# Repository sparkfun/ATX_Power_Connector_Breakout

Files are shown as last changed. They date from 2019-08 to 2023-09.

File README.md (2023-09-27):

SparkFun ATX Power Connector Breakout - 12V/5V (4-pin)
========================================

<table class="table table-hover table-striped table-bordered">
  <tr align="center">
   <td><a href="https://www.sparkfun.com/products/15035">SparkFun ATX Power Connector Breakout - 12V/5V (4-pin)</a></td>
   <td><a href="https://www.sparkfun.com/products/15701">SparkFun ATX Power Connector Breakout Kit - 12V/5V (4-pin)</a></td>
  </tr>
  <tr align="center">
    <td><i>SparkFun ATX Power Connector Breakout - 12V/5V (4-pin) <a href="https://www.sparkfun.com/products/15035">(BOB-15035)</a></i></td>
    <td><i>SparkFun ATX Power Connector Breakout Kit - 12V/5V (4-pin) <a href="https://www.sparkfun.com/products/15701">(KIT-15701)</a></i></td>
  </tr>
</table>

Do you need to power a project with 12V and 5V from one power supply? The ATX power connector breakout board breaks out the standard 4-pin computer peripheral port when mated with an ATX connector [(PRT-15700)](https://www.sparkfun.com/products/15700) for your 12V and 5V devices! Once you have chosen a power supply (whether it be an ATX power supply or the 12V/5V wall adapter), you're ready to give your project some life! This kit has everything you need (including a 12V/5V power supply) to solder together an ATX breakout and screw terminals to power your project directly or pump power into a breadboard using standard headers. 

ATX power supplies usually have a number of power connectors available to power components for a desktop computer.  One of these connectors is the 4-pin power connector, which is intended to power 12V and 5V computer peripherals (such as disk drives). Depending on the manufacturer of the power supply, the quantity of each connector can vary. If you want to easily grab some juice for your project from this connector, you'll need to connect the breakout board to this port.

**Note:** For the kit version, assembly and a basic knowledge of soldering will be required. The ATX power connector breakout does not come pre-assembled.

Repository Contents
-------------------

* **/Documentation** - Data sheets, additional product information
* **/Hardware** - Eagle design files (.brd, .sch)

Documentation
-------------------

* **[Hookup Guide](https://learn.sparkfun.com/tutorials/atx-power-connector-4-pin-breakout-hookup-guide)**
* **[Fritzing Part](https://github.com/sparkfun/Fritzing_Parts/blob/main/products/15035-sfe_ATX_Power_Connector_Breakout_12V_5V_Power_Supply.fzpz)**

Product Versions
----------------
* [KIT-15035](https://www.sparkfun.com/products/15701)
* [BOB-15035](https://www.sparkfun.com/products/15035)

License Information
-------------------

This product is _**open source**_! 

Please review the LICENSE.md file for license information. 

If you have any questions or concerns on licensing, please contact technical support on our [SparkFun forums](https://forum.sparkfun.com/viewforum.php?f=152).

Distributed as-is; no warranty is given.

- Your friends at SparkFun.

_<COLLABORATION CREDIT>_

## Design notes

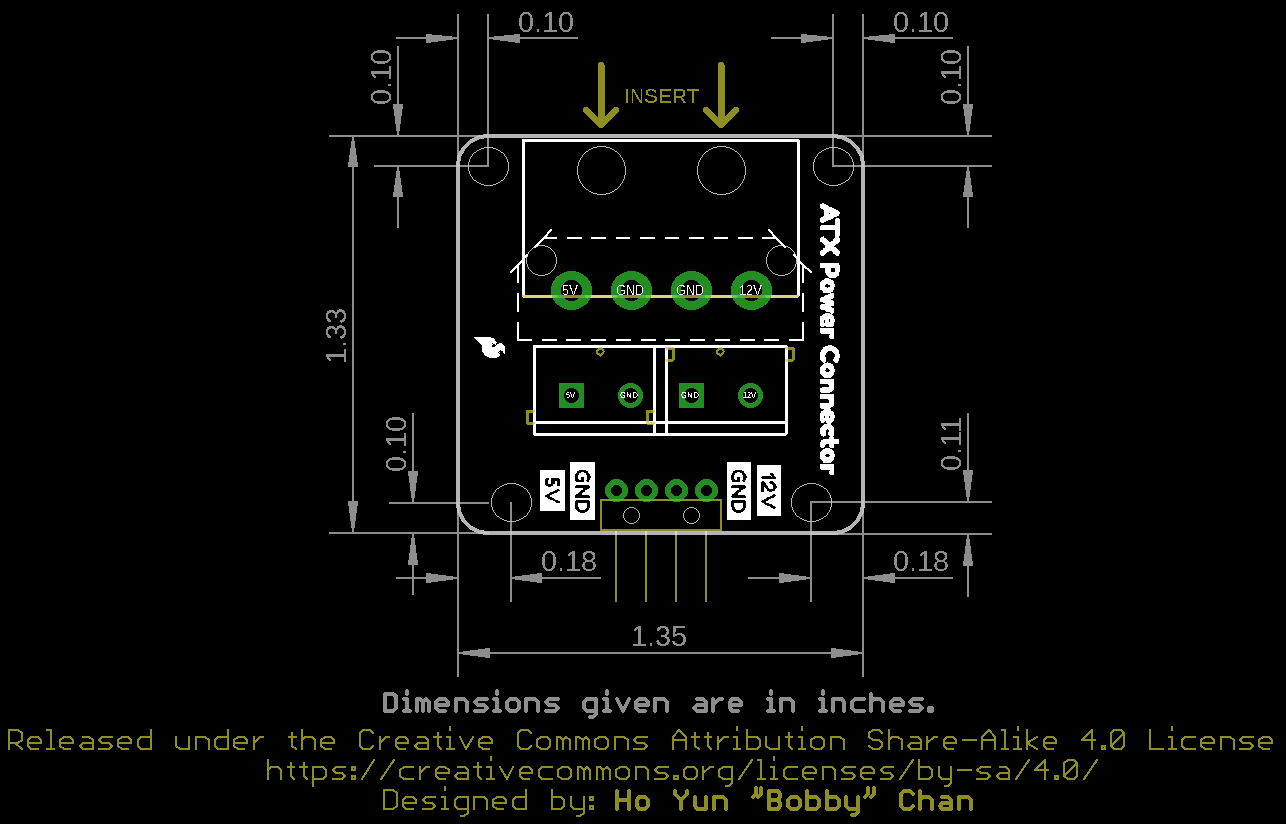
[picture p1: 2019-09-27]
Documentation/SparkFun_ATX_Power_Connect_Board_Dimension.png

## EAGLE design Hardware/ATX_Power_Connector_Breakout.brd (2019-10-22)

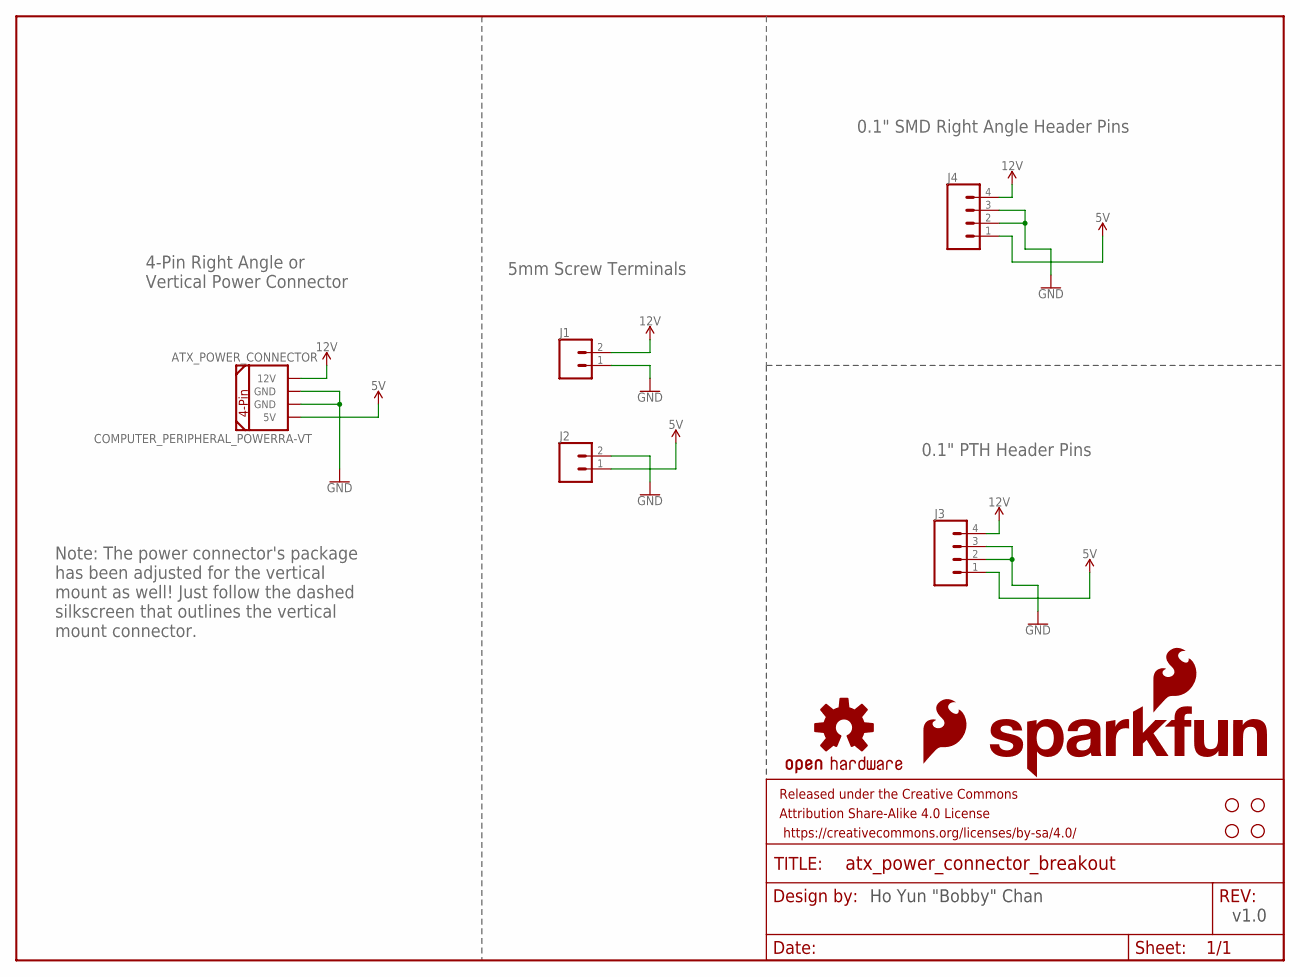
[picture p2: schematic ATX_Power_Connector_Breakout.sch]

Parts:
ATX_POWER_CONNECTOR: COMPUTER_PERIPHERAL_POWERRA-VT; COMPUTER-PERIPHERAL-POWER-RA-VT
FRAME1: FRAME-LETTER; CREATIVE_COMMONS
H1, H2, H3, H4: STAND-OFF
J1, J2: CONN_025MM; SCREWTERMINAL-5MM-2
J3: CONN_04; 1X04
J4: CONN_04SMD; 1X04_SMD_RA_MALE
LOGO1: OSHW-LOGOS; OSHW-LOGO-S
LOGO2: SFE_LOGO_NAME_FLAME.1_INCH; SFE_LOGO_NAME_FLAME_.1
LOGO3: SFE_LOGO_FLAME.1_INCH; SFE_LOGO_FLAME_.1

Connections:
5V: ATX_POWER_CONNECTOR.5V, J2.1, J3.1, J4.1
12V: ATX_POWER_CONNECTOR.12V, J1.2, J3.4, J4.4
GND: ATX_POWER_CONNECTOR.GND@1 (GND), ATX_POWER_CONNECTOR.GND@2 (GND), J1.1, J2.2, J3.2, J3.3, J4.2, J4.3

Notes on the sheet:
Ho Yun "Bobby" Chan
v1.0
5mm Screw Terminals
0.1" PTH Header Pins
4-Pin Right Angle or Vertical Power Connector
0.1" SMD Right Angle Header Pins
Note: The power connector's package has been adjusted for the vertical mount as well! Just follow the dashed silkscreen that outlines the vertical mount connector.

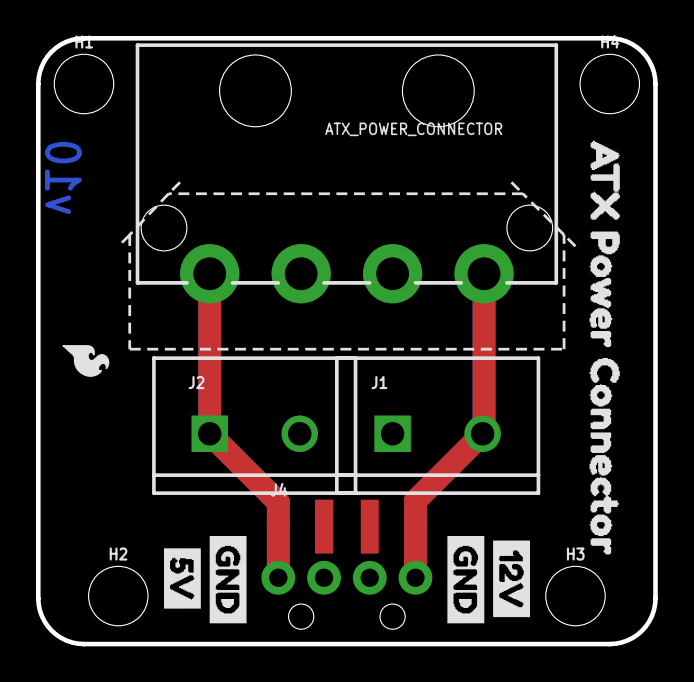
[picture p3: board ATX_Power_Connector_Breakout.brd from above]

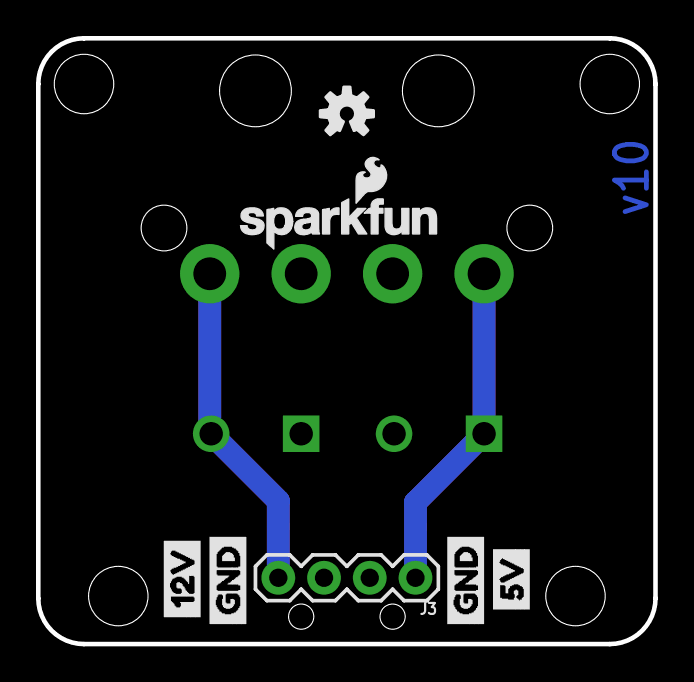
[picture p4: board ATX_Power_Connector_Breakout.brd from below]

Board: 2 copper layers, 34.3 x 33.7 mm, 22 parts (7 on the bottom side), 3 nets.

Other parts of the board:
U$1, U$5: 12V0
U$2, U$8: 5V0
U$3, U$4, U$6, U$7: GND0
U$9: ATX_POWER_CONNECTOR0

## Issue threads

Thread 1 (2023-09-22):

Missing Fritzing file?

erichiggins, 2023-09-22:
Is there a Fritzing file available for this breakout board? I'm not seeing it within the Fritzing parts library.

bboyho, 2023-09-22:
Hi!

Hmm, looking at our [Fritzing parts repository](https://github.com/sparkfun/Fritzing_Parts/tree/main/products), I don't believe we have made one for that specific part yet. This seems like a simple part, I might have some time to make the part within the next month.

I'll have to place the design files through the Eagle-to-Fritzing converter and see what happens.

erichiggins, 2023-09-23:
Appreciate the help, thank you!

bboyho, 2023-09-27:
The Eagle-to-Fritzing converter spit out some of the board. I had to manually add some PTHs and pads to make it functional for all layers. I added some 5mm screw terminals in the breadboard but kept the ATX connector off since there was a horizontal and vertical part. Other than that, it should be functional. =)

https://github.com/sparkfun/Fritzing_Parts/blob/main/products/15035-ATX_Power_Connector_Breakout_12V_5V_Power_Supply.fzpz

Closed 2023-09-27.

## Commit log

2018-07-03 Add Initial Eagle Files
    [Molex_Breakout_Board.brd, Molex_Breakout_Board.sch]
2019-03-19 Update Board File
    -update text to standard buzzard
    -remove negasilk and replace with dashed outline of straight molex connector
    -add top thick trace on top
    -adjust package so that NC is GND
    -remove jumper on bottom of board
    -adjust size so mounting holes are not in the way of right angle connector
    -adjust measurements based on new size
    -adjust text so that it is not overlapping on the mounting holes
    [Molex_Breakout_Board.brd, Molex_Breakout_Board.sch]
2019-03-25 Update Board
    -use buzzard text for board's name
    -adjust ground pour "width" to 0.01" to fit SparkFun DRC standards
    [Molex_Breakout_Board.brd, Molex_Breakout_Board.sch]
2019-04-02 Update Text
    - Adjust ratio based on SFE text standards
    - Adjust sections in schematic for aesthetics
    [Molex_Breakout_Board.brd, Molex_Breakout_Board.sch]
2019-04-05 Shorten Length of Voltage Rails
    [Molex_Breakout_Board.brd]
2019-04-05 Update Molex_Breakout_Board.sch
    Approve schematic error
    [Molex_Breakout_Board.sch]
2019-05-30 Update Molex_Breakout_Board.brd
    - Update Molex through holes for straight connector
    - adjust 5mm screw terminal spacing when slide-locking them together
    - reroute traces based on adjustments
    [Molex_Breakout_Board.brd]
2019-08-19 Update Molex Connector Package
    - Move Straight Connector Silkscreen into RA connector package
    - Adjust Dill Hit of package to about 1.82 mm for straight connector for more tolerance depending on supplier
    [Molex_Breakout_Board.brd, Molex_Breakout_Board.sch]
2019-08-19 Update Molex_Breakout_Board.sch
    - Add Note for vertical mount molex connector
    [Molex_Breakout_Board.sch]
2019-08-27 Rename Board and Files
    [ATX_Power_Breakout.brd, ATX_Power_Breakout.sch]
2019-08-27 Rename File
    [ATX_Power_Connector_Breakout.brd, ATX_Power_Connector_Breakout.sch]
2019-08-28 Update ATX_Power_Connector_Breakout.brd
    - move two mounting holes for Qwiic 1"x1"
    - adjust silkscreen for product name font size
    [ATX_Power_Connector_Breakout.brd]
2019-09-27 Add Dimensions
    [ATX_Power_Connector_Breakout.brd, ATX_Power_Connector_Breakout.sch]
2019-10-22 Update Device
    - Update device to link to latest SparkFun Eagle's Connector Library
    [ATX_Power_Connector_Breakout.brd, ATX_Power_Connector_Breakout.sch]

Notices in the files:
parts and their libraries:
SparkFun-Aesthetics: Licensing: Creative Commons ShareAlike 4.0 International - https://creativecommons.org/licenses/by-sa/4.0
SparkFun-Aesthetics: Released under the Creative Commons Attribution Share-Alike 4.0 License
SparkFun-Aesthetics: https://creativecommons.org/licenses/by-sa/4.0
